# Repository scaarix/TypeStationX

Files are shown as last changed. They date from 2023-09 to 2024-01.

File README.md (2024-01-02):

# TypeStationX

AKA PS2-KB

# Update
PCB arrived now waiting for parts to arrive

# About
a single mcu RP2040 based keyboard that uses ps2 controller connectors

currently in development
when ordering pcbs make sure to upload and order both<a href="https://github.com/scaarix/ps2-keyboard-thing/blob/main/TypeStationX/gerbers/left.zip"> left</a> and <a href="https://github.com/scaarix/ps2-keyboard-thing/blob/main/TypeStationX/gerbers/left.zip">right</a> sides
# Findings:
I don't think there are any ps2 controller extension cables that have all 9 pins available. Because one of the pins aren't needed, they get rid of it to save a few cents. So making your own cable is nessisary.
If i make a rev2 (i probably won't) it would most likely have an IO expander on the other half using spi (6 pins on the connector) so that I can use the cable instead of having to create my own.

# TODO:
- [x] Create firmware
- [ ] Create build guide
- [ ] Buy pcb and assemble
- [ ] Add photos

# Parts
| Part name | Amount |Link |
| --- | --- | --- |
| KB2040 | 1 | <a href="https://www.adafruit.com/product/5302">Adafruit</a>|
| 1N4148W Diode | 36 |<a href="https://www.adafruit.com/product/5099">AdaFruit</a> |
| 1N4148TR Diode (THT) | 36 | <a href="https://www.aliexpress.com/item/32729204179.html">Aliexpress</a>|
| Female controller ports | 2 |<a href="https://www.aliexpress.com/item/1005005547168036.html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">Aliexpress</a>|
| Male Controller Port | 2 |<a href="https://www.aliexpress.com/item/1005003234151343.html">Aliexpress</a>|
| Your choice of mx switches | 36 | |
| 6mmx3mm magnets | 10 |<a href="https://www.amazon.com/FINDMAG-Magnets-Magnetic-Whiteboard-Refrigerator/dp/B08M3YP56J">Amazon</a>|

WARNING: Your PS2 controller cable extension may only have 8 out of the 9 pins needed. You can dissasemble the connector piece and add another pin yourself. Depending on your case it may be better just to use two ps2 controllers to make your own cable!

# HUGE THANKS TO
Chewiedies for helping make the stunning case :)

Corvett for giving me the idea for using the ps2 connector to bridge the two halfs of the keyboard

The absolem server for putting up with my sometimes stupid questions and helping me along the way

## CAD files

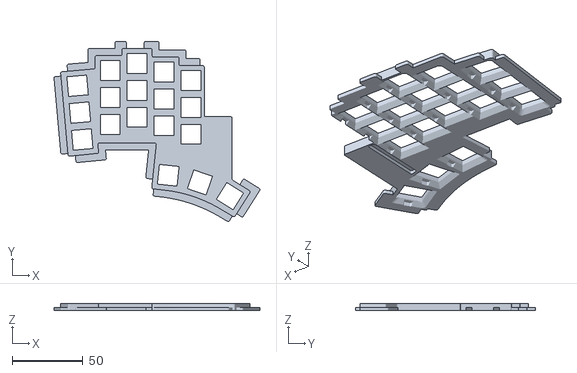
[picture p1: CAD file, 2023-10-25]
Case/TypstationX/left/SwitchPlateleftv1.stl
145.6 x 127.4 x 5.00

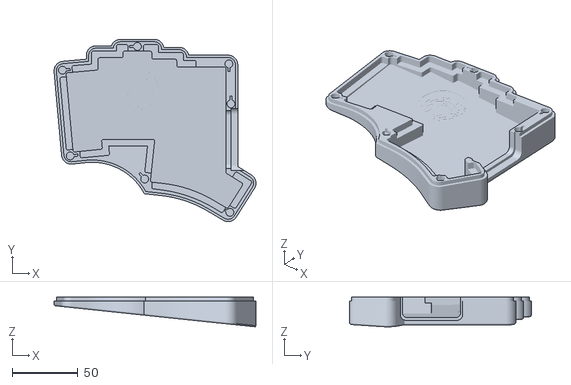
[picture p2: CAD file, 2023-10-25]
Case/TypstationX/left/Baseleft6degv1.stl
154.2 x 139.2 x 22.7

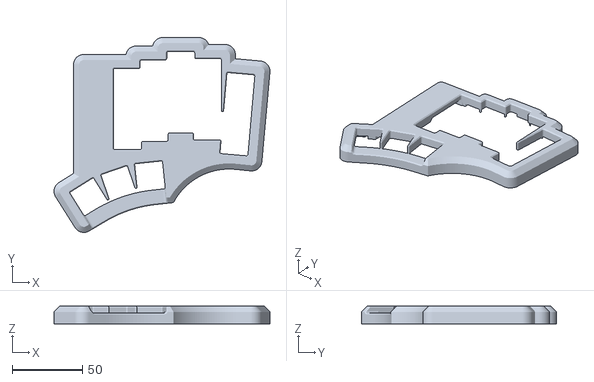
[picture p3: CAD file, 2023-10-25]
Case/TypstationX/right/Lid-right-v1.stl
154.2 x 139.2 x 12.6

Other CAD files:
Case/TypstationX/right/SwitchPlate-right-v1.stl
Case/TypstationX/left/Lidleftv1.stl
Case/TypstationX/right/Base-right-6deg-v1.stl

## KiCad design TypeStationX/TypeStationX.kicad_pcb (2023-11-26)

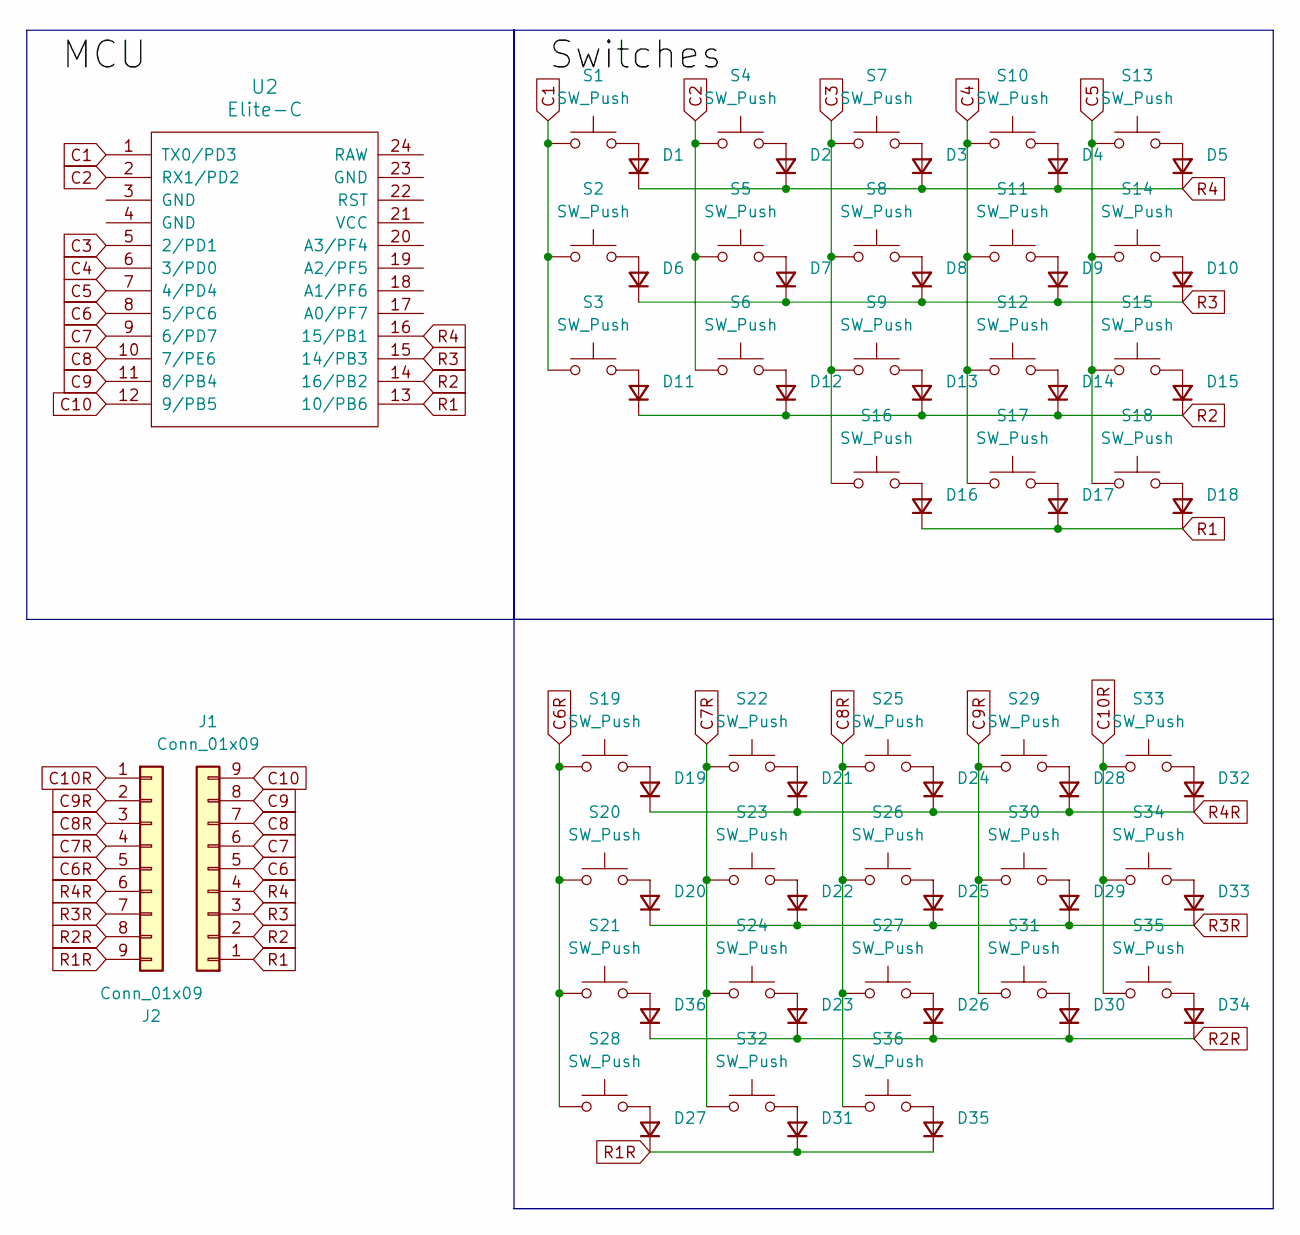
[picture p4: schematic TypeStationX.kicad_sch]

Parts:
D1, D2, D3, D4, D5, D6, D7, D8, D9, D10, D11, D12, D13, D14, D15, D16, D17, D18, D19, D20, D21, D22, D23, D24, D25, D26, D27, D28, D29, D30, D31, D32, D33, D34, D35, D36: D_Small; D3_TH_SMD_v2
J1, J2: Conn_01x09; 1x9 4mm
S1, S2, S3, S4, S5, S6, S7, S8, S9, S10, S11, S12, S13, S14, S15, S16, S17, S18, S19, S20, S21, S22, S23, S24, S25, S26, S27, S28, S29, S30, S31, S32, S33, S34, S35, S36: SW_Push; SW_Cherry_MX_PCB_1.00u
U2: Elite-C; ArduinoProMicro

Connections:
C1: S1.1, S2.1, S3.1, U2.1 (TX0/PD3)
C2: S4.1, S5.1, S6.1, U2.2 (RX1/PD2)
C3: S7.1, S8.1, S9.1, S16.1, U2.5 (2/PD1)
C4: S10.1, S11.1, S12.1, S17.1, U2.6 (3/PD0)
C5: S13.1, S14.1, S15.1, S18.1, U2.7 (4/PD4)
C6: J1.5, U2.8 (5/PC6)
C6R: J2.5, S19.1, S20.1, S21.1, S28.1
C7: J1.6, U2.9 (6/PD7)
C7R: J2.4, S22.1, S23.1, S24.1, S32.1
C8: J1.7, U2.10 (7/PE6)
C8R: J2.3, S25.1, S26.1, S27.1, S36.1
C9: J1.8, U2.11 (8/PB4)
C9R: J2.2, S29.1, S30.1, S31.1
C10: J1.9, U2.12 (9/PB5)
C10R: J2.1, S33.1, S34.1, S35.1
unnamed: D1.2 (A), S1.2
unnamed: D2.2 (A), S4.2
unnamed: D3.2 (A), S7.2
unnamed: D4.2 (A), S10.2
unnamed: D5.2 (A), S13.2
unnamed: D6.2 (A), S2.2
unnamed: D7.2 (A), S5.2
unnamed: D8.2 (A), S8.2
unnamed: D9.2 (A), S11.2
unnamed: D10.2 (A), S14.2
unnamed: D11.2 (A), S3.2
unnamed: D12.2 (A), S6.2
unnamed: D13.2 (A), S9.2
unnamed: D14.2 (A), S12.2
unnamed: D15.2 (A), S15.2
unnamed: D16.2 (A), S16.2
unnamed: D17.2 (A), S17.2
unnamed: D18.2 (A), S18.2
unnamed: D19.2 (A), S19.2
unnamed: D20.2 (A), S20.2
unnamed: D21.2 (A), S22.2
unnamed: D22.2 (A), S23.2
unnamed: D23.2 (A), S24.2
unnamed: D24.2 (A), S25.2
unnamed: D25.2 (A), S26.2
unnamed: D26.2 (A), S27.2
unnamed: D27.2 (A), S28.2
unnamed: D28.2 (A), S29.2
unnamed: D29.2 (A), S30.2
unnamed: D30.2 (A), S31.2
unnamed: D31.2 (A), S32.2
unnamed: D32.2 (A), S33.2
unnamed: D33.2 (A), S34.2
unnamed: D34.2 (A), S35.2
unnamed: D35.2 (A), S36.2
unnamed: D36.2 (A), S21.2
R1: D16.1 (K), D17.1 (K), D18.1 (K), J1.1, U2.13 (10/PB6)
R1R: D27.1 (K), D31.1 (K), D35.1 (K), J2.9
R2: D11.1 (K), D12.1 (K), D13.1 (K), D14.1 (K), D15.1 (K), J1.2, U2.14 (16/PB2)
R2R: D23.1 (K), D26.1 (K), D30.1 (K), D34.1 (K), D36.1 (K), J2.8
R3: D6.1 (K), D7.1 (K), D8.1 (K), D9.1 (K), D10.1 (K), J1.3, U2.15 (14/PB3)
R3R: D20.1 (K), D22.1 (K), D25.1 (K), D29.1 (K), D33.1 (K), J2.7
R4: D1.1 (K), D2.1 (K), D3.1 (K), D4.1 (K), D5.1 (K), J1.4, U2.16 (15/PB1)
R4R: D19.1 (K), D21.1 (K), D24.1 (K), D28.1 (K), D32.1 (K), J2.6

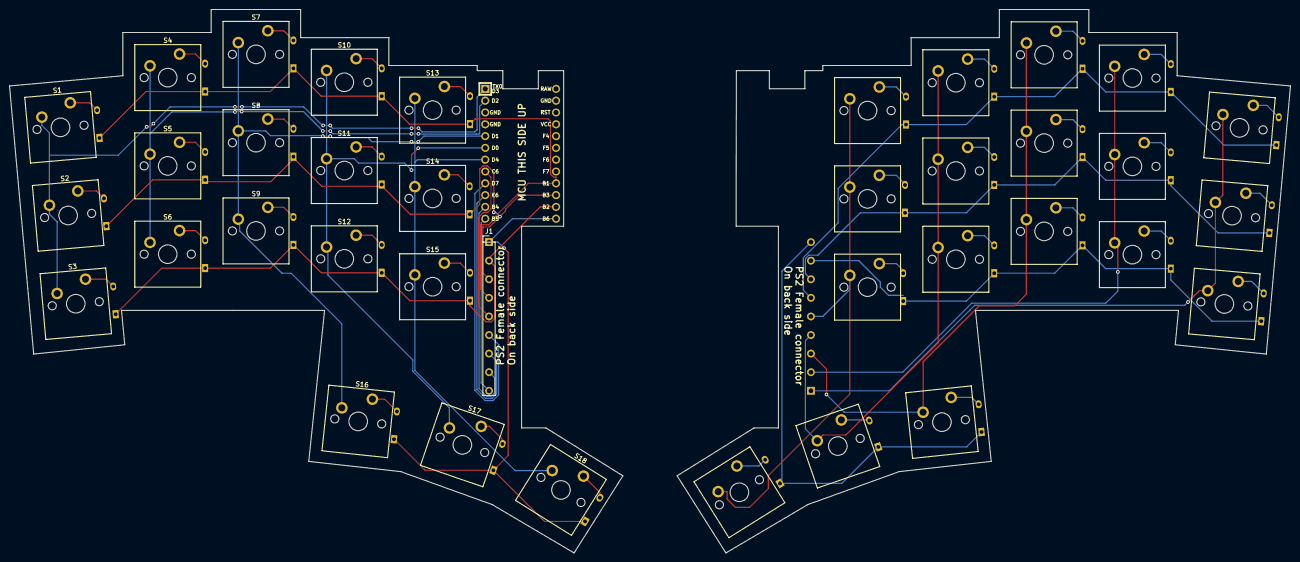
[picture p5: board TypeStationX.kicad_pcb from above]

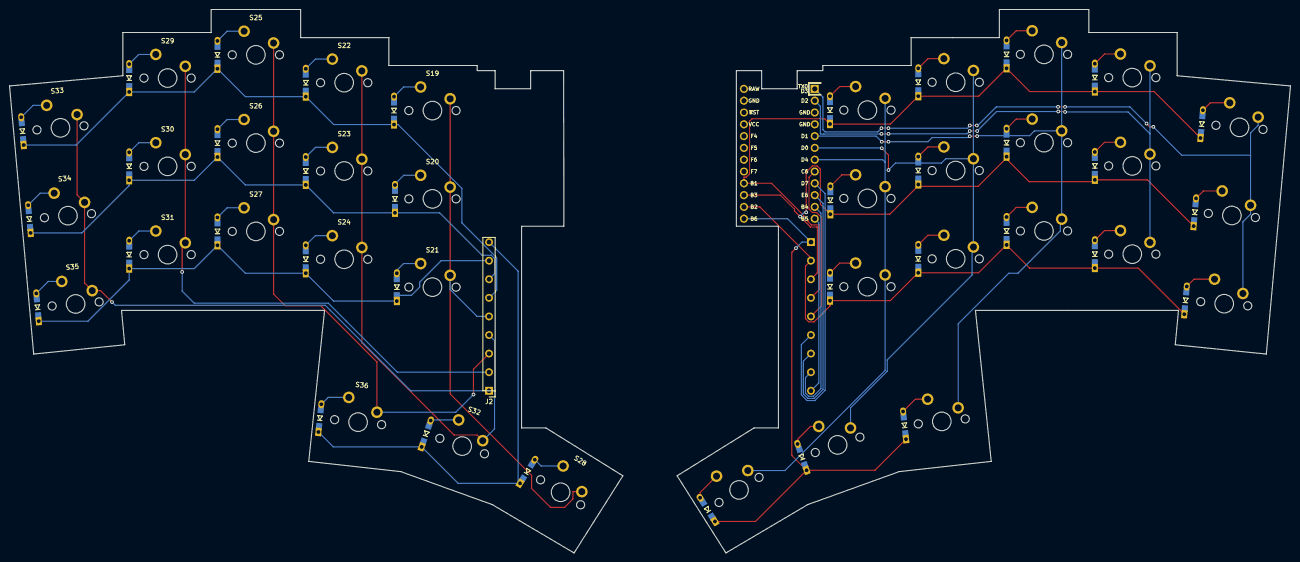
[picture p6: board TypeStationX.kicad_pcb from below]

Board: 2 copper layers, 275.7 x 117.0 mm, 75 parts (37 on the bottom side), 59 nets.

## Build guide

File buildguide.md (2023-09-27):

# Build guide
# CURRENTLY IN PROGRESS

1. Cut off male end of cable and cut female end of donor cable
   Make sure there is some cable left to help distinguish colors    
2. Solder female end to cable

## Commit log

2023-11-24 Updated PCB to have through hole diode support
    [TypeStationX - Right-B_Cu.gbr, TypeStationX - Right-B_Mask.gbr, TypeStationX - Right-B_Paste.gbr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]
2023-11-26 Fixed diodes to be on the same side on both halves of the keyboard
    [TypeStationX-B_Cu.gbl, TypeStationX-B_Mask.gbs, TypeStationX-B_Paste.gbp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]
